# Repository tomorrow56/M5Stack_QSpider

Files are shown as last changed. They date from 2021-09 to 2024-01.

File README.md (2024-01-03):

# M5Stack_QSpider

## Quadruped Spider Robot for M5Stack
It is a quadruped walking robot using M5Stack and nine toy servos (SG90). It utilizes a custom servo module board for M5Stack equipped with PCA9685.

M5Stackとトイサーボ(SG90)x9個を使用した四脚歩行ロボットです。PCA9685を搭載したM5Stack用の自作サーボモジュール基板を使用しています。

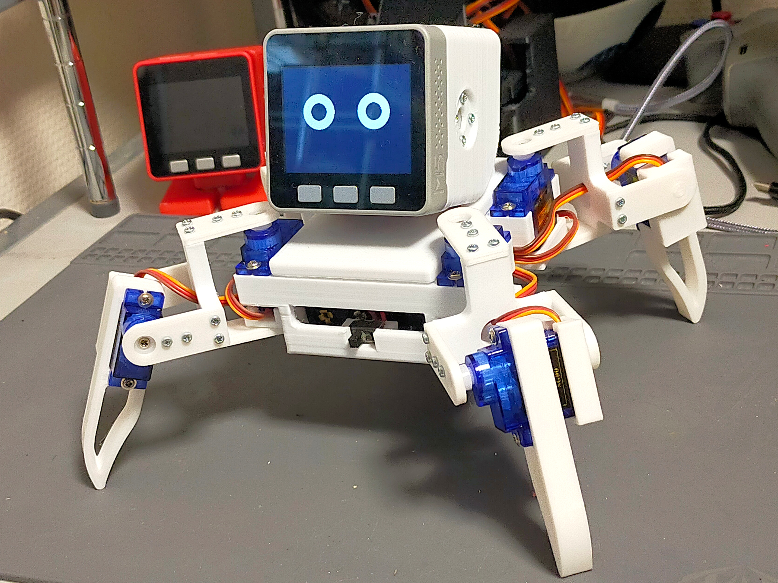
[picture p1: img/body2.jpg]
Body


Botttom View
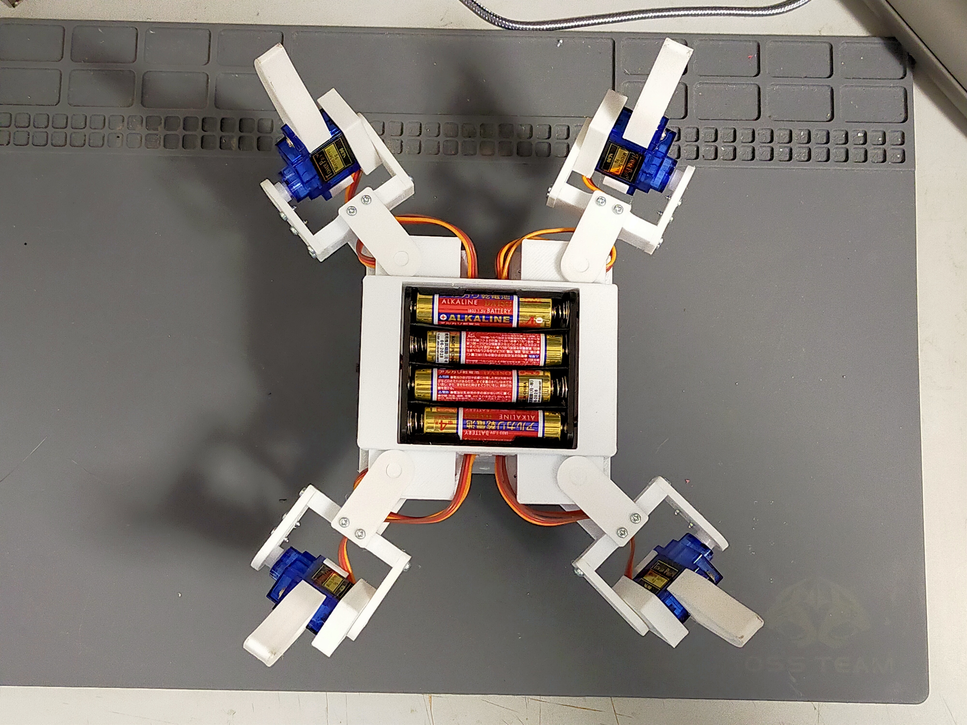
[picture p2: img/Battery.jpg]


### 3D Print Data
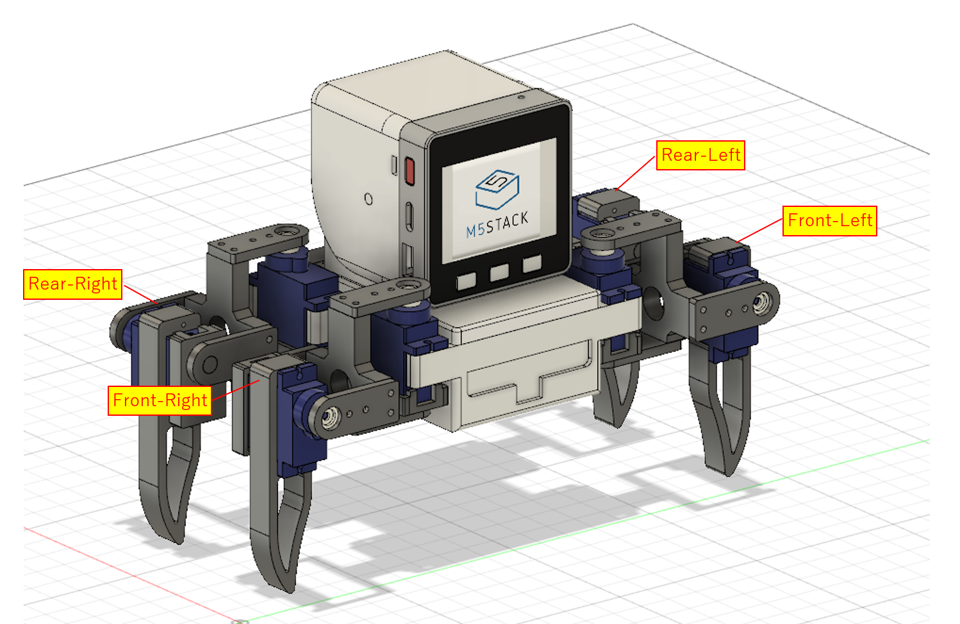
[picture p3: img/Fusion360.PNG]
Design


The 3D print data is available below. Please print four sets of parts from the 'leg' folder, as each set corresponds to one leg.

3Dプリント用のデータは以下にあります。legフォルダ以下の部品は1本分なので4個印刷してください。

[STL Data](3dprint/)

The fully assembled main body and each leg (two types, diagonal combinations) is uploaded in STEP format. Please refer to them during assembly.

組立済の本体全体・各脚(対角の組合せで2種類)はSTEP形式でアップロードしてありますので、参考にしてください。

[STEP Data](3dprint/step)

### M5Stack Servo Driver Module M5Stack用サーボモジュール基板 
The circuit diagram and Gerber data have been published below for public access.

回路図とガーバーデータは以下で公開しています。

<https://github.com/tomorrow56/M5Stack_Servo_Driver>

### Parts needed (excluding 3D print parts)
* M5Stack Basic x 1
* [SG-90](https://akizukidenshi.com/catalog/g/gM-08761/) X 9
* [Battery Holder for 4x AA](https://akizukidenshi.com/catalog/g/gP-03087/) (For servo power)
* [NP-40 Lithium-ion Battery for Cameras](https://amzn.to/3S4qocj) or a similarly sized one (For M5Stack power)
* [Slide Switch 1 Circuit 2 Contacts](https://akizukidenshi.com/catalog/g/gP-15707/)
* M2x8mm Tapping Screws (Approximately 40)
* Wiring Lead for connections

### 必要な部品 (3Dプリント部品以外) 
* M5Stack Basic x 1
* [SG-90](https://akizukidenshi.com/catalog/g/gM-08761/) X 9
* [電池ボックス単4×4本](https://akizukidenshi.com/catalog/g/gP-03087/) (サーボ電源用)
* [カメラ用リチウムイオン電池 NP-40](https://amzn.to/3S4qocj) または同サイズのもの (M5Stack電源用)
* [スライドスイッチ 1回路2接点](https://akizukidenshi.com/catalog/g/gP-15707/)
* M2x8mmのタッピングビス(約40本)
* 配線用リード線

## ソフトウエア: Software
There are sketches for ArduinoIDE in the 'examples' folder. There are two types available for web interface and ESP-NOW.

ArduinoIDE用のスケッチがexample以下にあります。Webインターフェース用とESP-NOW用の2種類があります。

### Controler with Web Interface Webインターフェース
It starts as a WiFi access point and can be controlled from a web browser.

WiFiのアクセスポイントとして起動し、Webブラウザからコントロールできます。

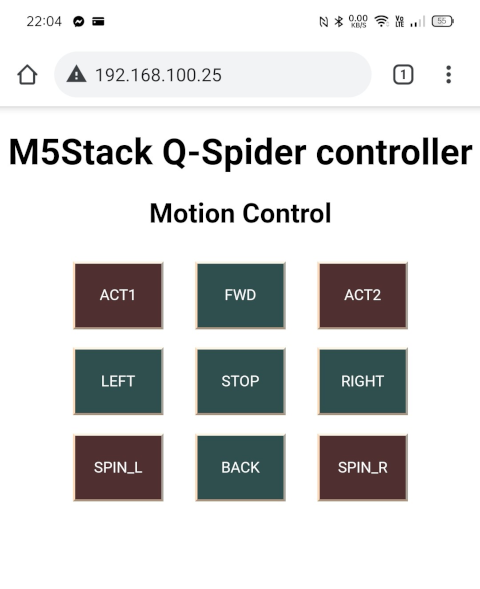
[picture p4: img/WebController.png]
Controller


### Controller for ESP-NOW mode ESP-NOW用コントローラ
The source code for the ESP-NOW controller is available below. Here, a modified Famicom controller is used.

ESP-NOW用コントローラのソースコードは以下にあります。ここではファミコン用コントローラを改造して使用しています。

<https://github.com/tomorrow56/M5AtomPad>

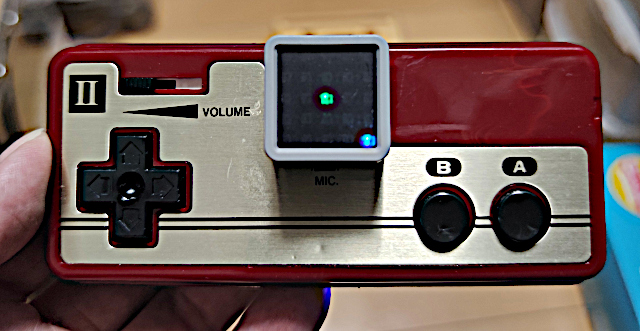
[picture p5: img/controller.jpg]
M5AtomPad


### Protopedia
<https://protopedia.net/prototype/2464>

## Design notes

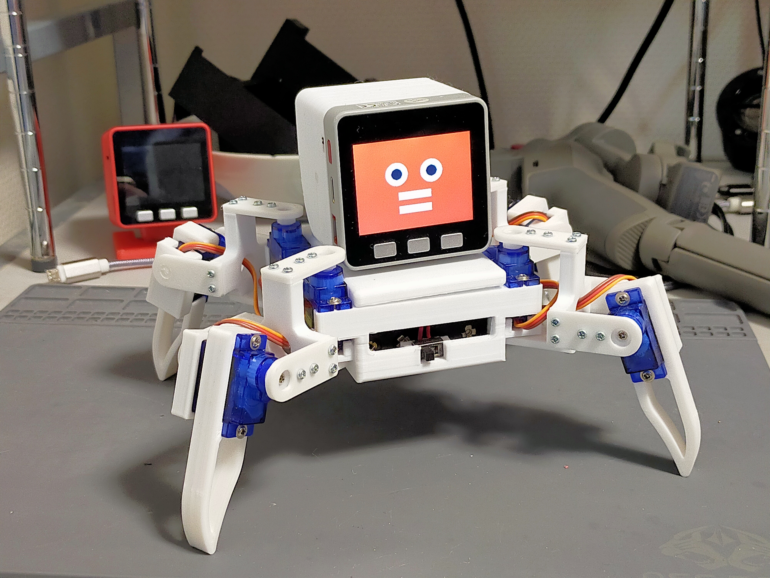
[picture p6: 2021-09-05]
img/body.jpg

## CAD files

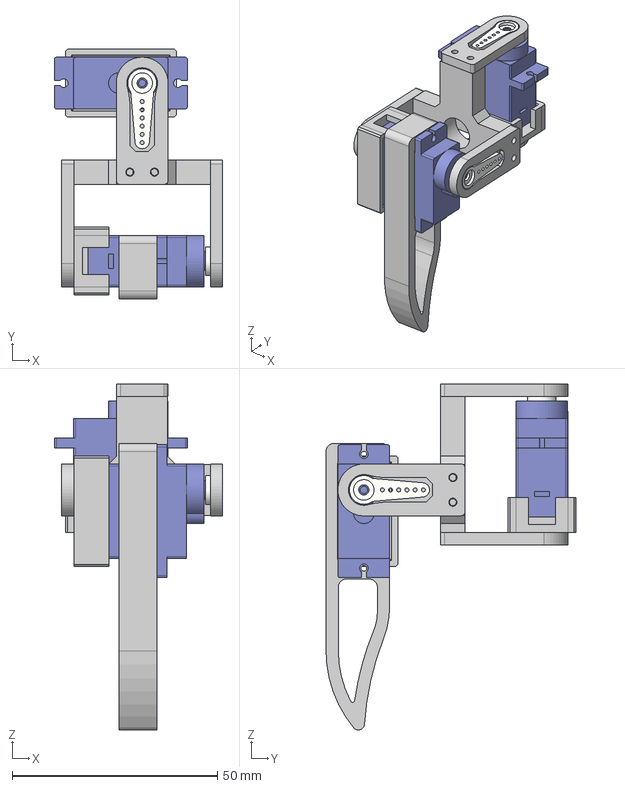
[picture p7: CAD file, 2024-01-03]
3dprint/step/assembled_Leg_FrontRight_RearLeft.step
41.0 x 60.9 x 84.3 mm
leg
SG90 v1
サーボホーン x 2
Foot_joint
shaft_top2
SG90 v1 (1)
shaft_top1
bottom_Spacer2
shaft_bottom2
shaft_bottom1
bottom_Spacer1

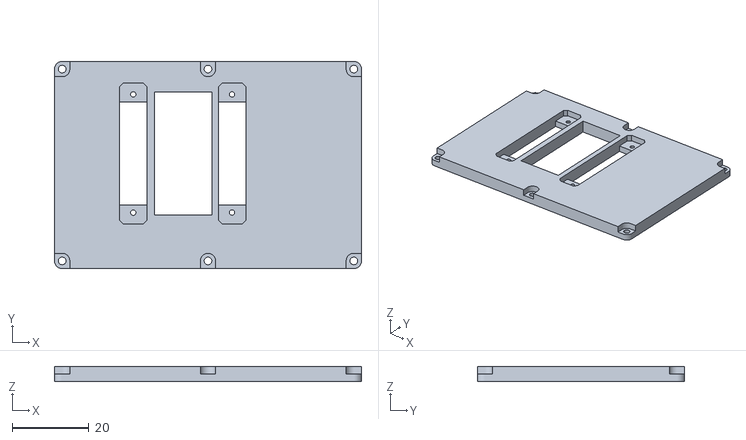
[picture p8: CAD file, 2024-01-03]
3dprint/body/body_top.stl
80.0 x 54.0 x 4.00

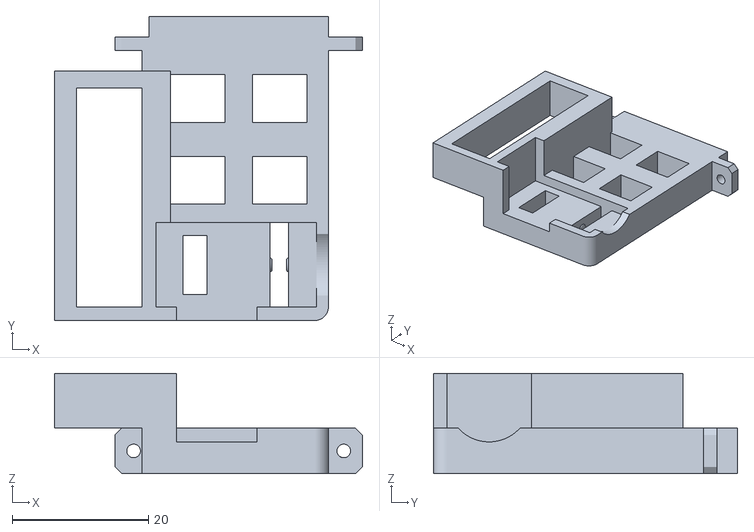
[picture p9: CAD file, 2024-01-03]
3dprint/bracket/bracket_front.stl
45.1 x 44.6 x 14.7

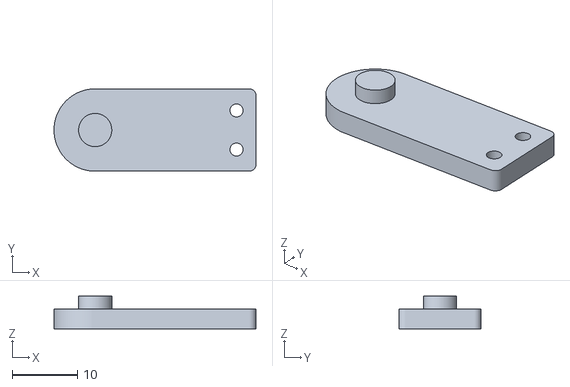
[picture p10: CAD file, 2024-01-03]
3dprint/leg/shaft_bottom1.stl
31.0 x 12.6 x 5.00

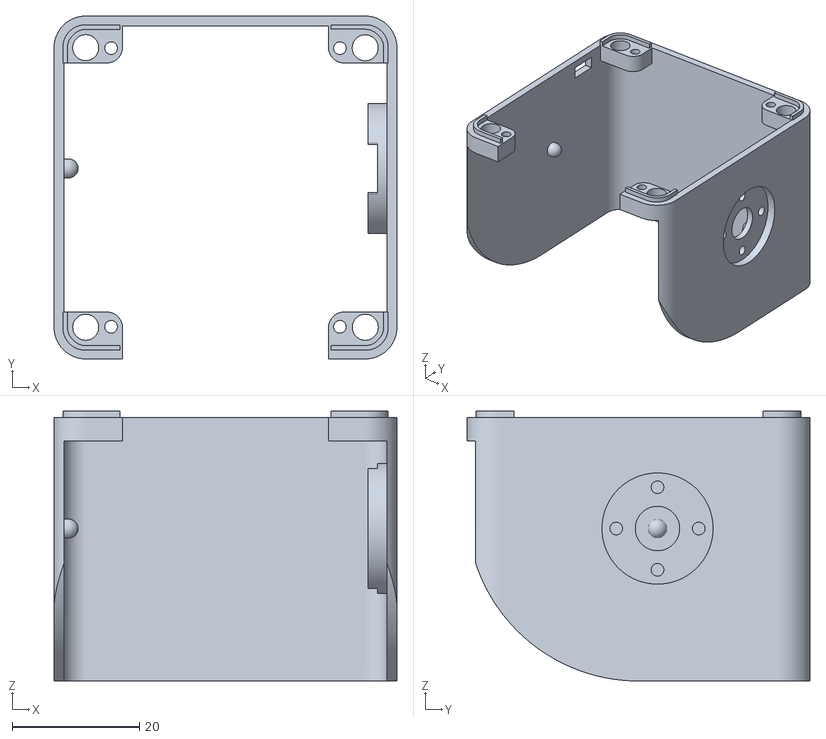
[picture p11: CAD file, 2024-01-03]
3dprint/shell/shell.stl
54.0 x 54.0 x 42.5

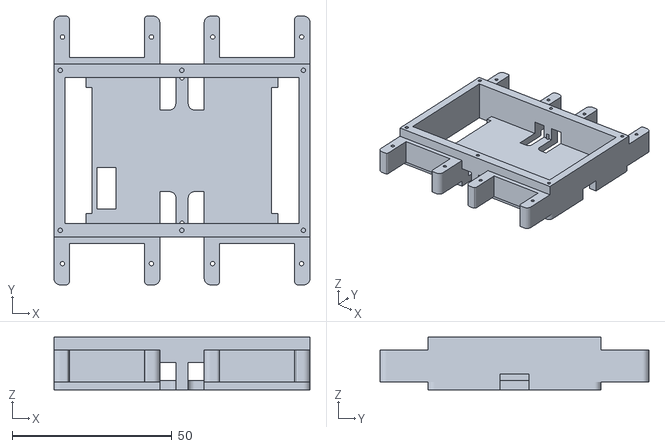
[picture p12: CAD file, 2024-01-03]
3dprint/body/body_bottom.stl
80.0 x 84.0 x 16.5

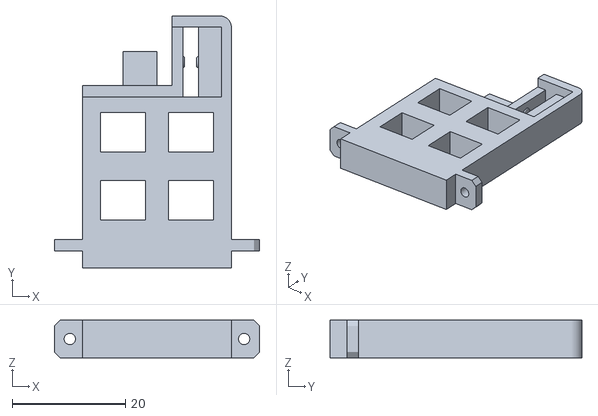
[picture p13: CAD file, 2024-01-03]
3dprint/bracket/bracket_rear.stl
36.3 x 44.6 x 6.65

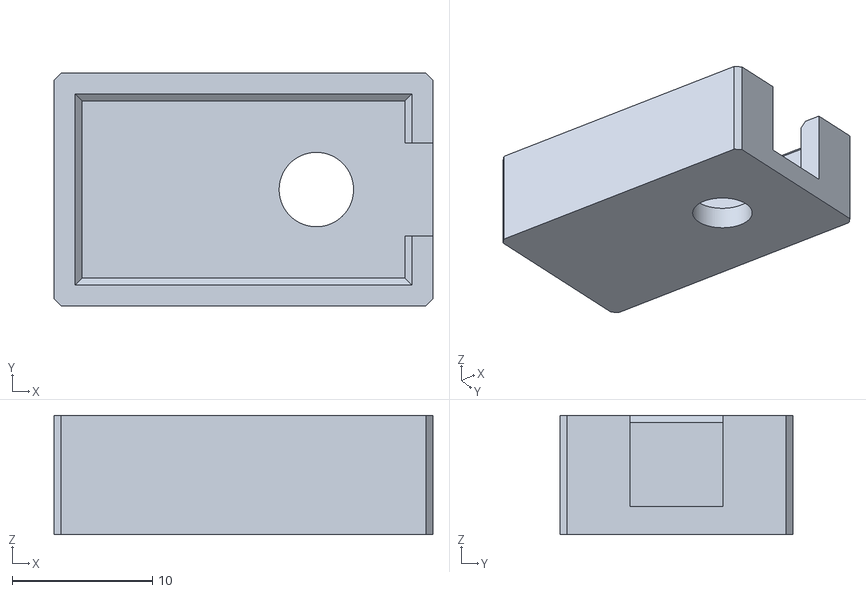
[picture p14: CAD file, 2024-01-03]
3dprint/leg/bottom_spacer1.stl
27.0 x 16.6 x 8.50

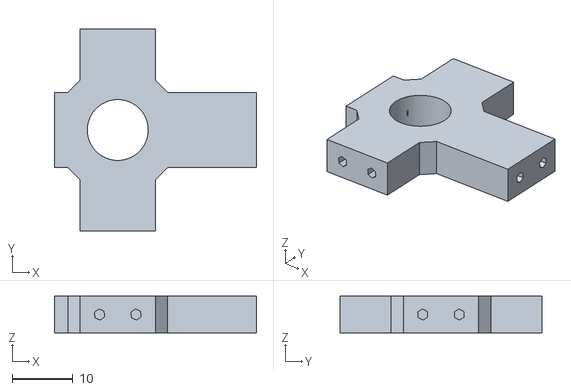
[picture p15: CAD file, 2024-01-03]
3dprint/leg/Foot_joint.stl
33.2 x 33.2 x 6.00

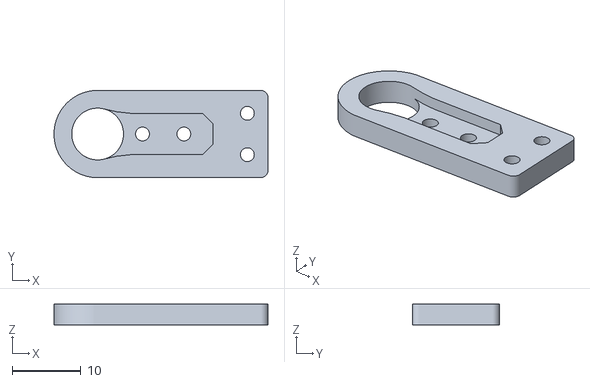
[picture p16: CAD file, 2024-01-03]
3dprint/leg/shaft_top1.stl
31.0 x 12.6 x 3.00

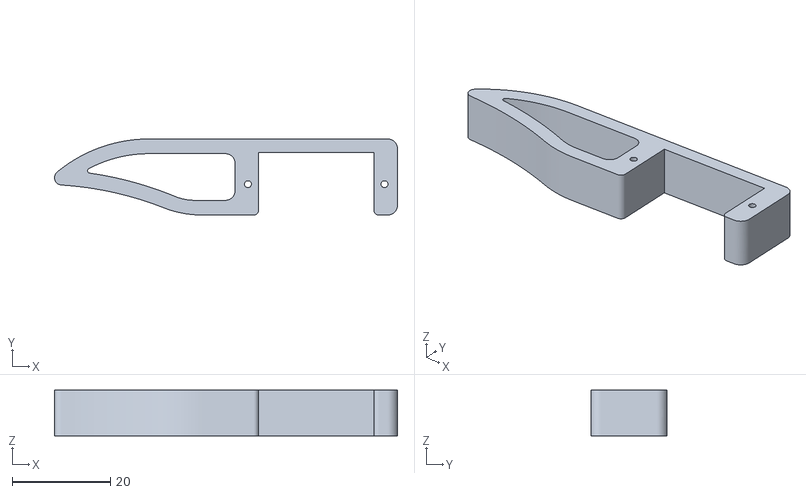
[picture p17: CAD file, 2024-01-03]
3dprint/leg/leg.stl
69.8 x 15.5 x 9.30

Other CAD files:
3dprint/step/assembled_Leg_FrontLeft_RearRight.step

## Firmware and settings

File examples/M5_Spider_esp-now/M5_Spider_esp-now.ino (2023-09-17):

#include <M5Stack.h>
#include "M5StackUpdater.h"
#include "ip5306.h"

#include <NESpad.h>
#include <esp_now.h>
#include <WiFi.h>

#include <Adafruit_PWMServoDriver.h>
#include "clappyavator.h"

//#define chgDET
#define DEBUG

/********************
 * NESPad parameters
 ********************/
#define nesStrobe 22
#define nesClock 19
#define nesData 23
NESpad nintendo = NESpad(nesStrobe,nesClock,nesData);
byte state = 0;

/********************
 * ESPNow settings
 ********************/
esp_now_peer_info_t slave;
int modeNES = 1;  //0:Multicast, 1:M5SpiderW, 2:M5SpiderB, other: Multicast
esp_err_t result;
boolean sending = false;

// command from Master
#define rNES_STOP 0
#define rNES_A 1
#define rNES_B 2
#define rNES_SELECT 3
#define rNES_START 4
#define rNES_UP 5
#define rNES_DOWN 6
#define rNES_LEFT 7
#define rNES_RIGHT 8

/********************************
* for Servo control
*********************************/
Adafruit_PWMServoDriver pwm = Adafruit_PWMServoDriver(0x72);

const uint8_t motorInterval = 30;  //[ms]

// Published values for SG90 servos; 0-180 deg
int minUs = 500;
int maxUs = 2400;

// Servo assign to each channel
#define FR0 0   // knees
#define FL0 2
#define RR0 6
#define RL0 8

#define FR1 1   // leg
#define FL1 3
#define RR1 7
#define RL1 9

#define TILT 4

// center position calibration(0-180 deg)
#define OFST 20

uint8_t CENT_FR0 = 90 + OFST;   // knees UP ++
uint8_t CENT_FL0 = 90 - OFST;   // knees UP --
uint8_t CENT_RR0 = 90 - OFST;   // knees UP --
uint8_t CENT_RL0 = 90 + OFST;   // knees UP ++

uint8_t CENT_FR1 = 90;   // leg forward ++
uint8_t CENT_FL1 = 90;   // leg forward --
uint8_t CENT_RR1 = 90;   // leg backword ++
uint8_t CENT_RL1 = 90;   // leg backword --

uint8_t CENT_TILT = 90; // up --

#define ROTATEIN  40
#define ROTATEOUT  150

int stp = 3;
int smooth = 5;

int stepInterval = 50;
int stepIntervalTurn = 100;

boolean moveFlag = false;
boolean walkFwdFlag = false;
boolean walkBckFlag = false;
boolean walkLeftFlag = false;
boolean walkRightFlag = false;
boolean spinLeftFlag = false;
boolean spinRightFlag = false;

//String Face = "/GALLERY/KumaMCN.jpg";

Avator *avator;

/************************************
 * Update Avator Task
 ************************************/
void avatorUpdate(void* arg) {
  int cnt = 0;
  while (1) {
    if(cnt == 0){
      //avator->openMouth(15);
    }
    if (cnt % 100 == 97){
      avator->openEye(false);
    }
    if (cnt % 100 == 0){
      avator->openEye(true);
      cnt = random(100);
    }
    cnt++;
    vTaskDelay(50);
  }
}

// 受信コールバック
void OnDataRecv(const uint8_t *mac_addr, const uint8_t *data, int data_len) {
  char macStr[18];
  snprintf(macStr, sizeof(macStr), "%02X:%02X:%02X:%02X:%02X:%02X",
           mac_addr[0], mac_addr[1], mac_addr[2], mac_addr[3], mac_addr[4], mac_addr[5]);
  Serial.printf("Last Packet Recv from: %s\n", macStr);
  Serial.printf("Last Packet Recv Data(%d): ", data_len);
  for ( int i = 0 ; i < data_len ; i++ ) {
    Serial.print(data[i]);
    Serial.print(" ");
  }
  Serial.println("");

// 送信元でフィルタ
  if((String)macStr == "4C:75:25:C6:F8:0C" || (String)macStr == "D8:A0:1D:5B:D1:AC"){
    if(data[0] == rNES_A){
      Serial.println("NES_A");
      spinRightFlag = true;
      #ifdef DEBUG
        Serial.println("Spin Right");
      #endif
    }else if(data[0] == rNES_B){
      Serial.println("NES_B");
      spinLeftFlag = true;
      #ifdef DEBUG
        Serial.println("Spin Left");
      #endif
    }else if(data[0] == rNES_SELECT){
      Serial.println("NES_SELECT");
    }else if(data[0] == rNES_START){
      Serial.println("NES_START");
    }else if(data[0] == rNES_UP){
      Serial.println("NES_UP");
      walkFwdFlag = true;
      #ifdef DEBUG
        Serial.println("Walk Forward");
      #endif
    }else if(data[0] == rNES_DOWN){
      Serial.println("NES_DOWN");
      walkBckFlag = true;
      #ifdef DEBUG
        Serial.println("Walk Backward");
      #endif
    }else if(data[0] == rNES_LEFT){
      Serial.println("NES_LEFT");
      walkLeftFlag = true;
      #ifdef DEBUG
        Serial.println("Walk Left");
      #endif
    }else if(data[0] == rNES_RIGHT){
      Serial.println("NES_RIGHT");
      walkRightFlag = true;
      #ifdef DEBUG
        Serial.println("Walk Right");
      #endif
    }else if(data[0] == rNES_STOP){
      Serial.println("NES_STOP");
      walkStop();
    }else{
      Serial.println("Unknown");
    }
  }
}

/************************************
 * Arduino block
 ************************************/
void setup() {
  // M5Stack::begin(LCDEnable, SDEnable, SerialEnable, I2CEnable);
  M5.begin(true, true, true, true);
  M5.Power.begin();
  M5.Power.setVinMaxCurrent(CURRENT_400MA);

  M5.Speaker.begin();
  M5.Speaker.mute();
  M5.Speaker.end();

  if(digitalRead(BUTTON_A_PIN) == 0) {
    Serial.println("Will Load menu binary");
    updateFromFS(SD);
    ESP.restart();
  }

  Serial.println("M5Stack Q-Spider esp-now");
  Serial.printf("NES mode: %d\n", modeNES);

/*
 * Servo setup
 */
 //modeNES 1:M5SpiderW, 2:M5SpiderB
  if(modeNES == 1){
    CENT_FR0 = 90 + OFST;   // knees UP ++
    CENT_FL0 = 90 - OFST;   // knees UP --
    CENT_RR0 = 90 - OFST;   // knees UP --
    CENT_RL0 = 90 + OFST;   // knees UP ++
    CENT_FR1 = 90;   // leg forward ++
    CENT_FL1 = 90;   // leg forward --
    CENT_RR1 = 90;   // leg backword ++
    CENT_RL1 = 90;   // leg backword --
    CENT_TILT = 100; // up --
  }else if(modeNES == 2){
    CENT_FR0 = 85 + OFST;   // knees UP ++
    CENT_FL0 = 85 - OFST;   // knees UP --
    CENT_RR0 = 95 - OFST;   // knees UP --
    CENT_RL0 = 90 + OFST;   // knees UP ++
    CENT_FR1 = 85;   // leg forward ++
    CENT_FL1 = 90;   // leg forward --
    CENT_RR1 = 90;   // leg backword ++
    CENT_RL1 = 95;   // leg backword --
    CENT_TILT = 110; // up --
  }

  pwm.begin();
  pwm.setPWMFreq(50);  // Analog servos run at 50 Hz updates
  delay(10);

  Serial.println("Ready");

  avator = new Avator();
  M5.Lcd.fillScreen(SECONDARY_COLOR);
//  M5.Lcd.drawJpgFile(SD, Face.c_str(), 0, 0, 320, 240);
  avator->init();

/*
 * Demo action
 */
//  servoDemo();
  servoHome();

  #ifdef chgDET
    if(getChargeEnable()){
      adjMode();
    }
  #endif

  walkStop();

  // ESP-NOW初期化
  WiFi.mode(WIFI_STA);
  WiFi.disconnect();
  if (esp_now_init() == ESP_OK) {
    Serial.println("ESPNow Init Success");
  } else {
    Serial.println("ESPNow Init Failed");
    ESP.restart();
  }

// ESP-NOWコールバック登録
  esp_now_register_recv_cb(OnDataRecv);

  // xTaskCreatePinnedToCore(タスクの関数名,"タスク名",スタックメモリサイズ,NULL,タスク優先順位,タスクハンドルポインタ,Core ID);
  // xTaskCreatePinnedToCore(func,"name",Stuck size,NULL,priority,Task pointer,Core ID)
  // Core ID: 0 or 1 or tskNO_AFFINITY
  xTaskCreatePinnedToCore(avatorUpdate, "Task0", 4096, NULL, 1, NULL, 0);
}

void loop(){
  M5.update();

  if(walkFwdFlag == true){
    if(moveFlag == false){
      walkFwdInit();
      moveFlag = true;
    }
    stepFoward();
  }

  if(walkBckFlag == true){
    if(moveFlag == false){
      walkBckInit();
      moveFlag = true;
    }
    stepBackward();
  }

  if(walkLeftFlag == true){
    if(moveFlag == false){
      walkLeftInit();
      moveFlag = true;
    }
    stepLeft();
  }

  if(walkRightFlag == true){
    if(moveFlag == false){
      walkRightInit();
      moveFlag = true;
    }
    stepRight();
  }

  if(spinLeftFlag == true){
    if(moveFlag == false){
      spinLeftInit();
      moveFlag = true;
    }
    stepSpinLeft();
  }

  if(spinRightFlag == true){
    if(moveFlag == false){
      spinRightInit();
      moveFlag = true;
    }
    stepSpinRight();
  }

}

/************************************
 * Demo Action
 ************************************/
// Servo Demo
void servoDemo(){
  servoHome();
  delay(500);

  servoLegOpen(45);
  delay(500);
  servoStandUp(70);
  delay(500);
  servoLegClose(45);
  delay(500);
  servoLayDown(70);
  delay(500);

  walkStop();
  delay(500);

  servoTilt(10);
  delay(500);
  servoTilt(0);
}

// Home position
void servoHome(){
  moveServo(TILT, 0);

  moveServo(FR1, 0);
  moveServo(FL1, 0);
  moveServo(RR1, 0);
  moveServo(RL1, 0);

  moveServo(FR0, 0);
  moveServo(FL0, 0);
  moveServo(RR0, 0);
  moveServo(RL0, 0);
}

/************************************
 * Stop
 ************************************/
void walkStop(){
  walkFwdFlag = false;
  walkBckFlag = false;
  walkLeftFlag = false;
  walkRightFlag = false;
  spinLeftFlag = false;
  spinRightFlag = false;

  moveFlag = false;
  walkEnd();

  #ifdef DEBUG
    Serial.println("Walk Stop");
  #endif
}

// END position
void walkEnd(){
  delay(stepInterval);
  servoLegFront(45);
  servoLegRear(45);
  servoKneesAll(70);
}

/************************************
 * Walk
 ************************************/
// Walk Forward
void walkFwdInit(){
  servoLegFront(45);
  servoLegRear(45);
  servoKneesAll(70);
  delay(stepInterval);

  // initial position for walk Forward
  moveServo(RL0, -50);
  moveServo(RL1, 0);
  delay(stepInterval);
  moveServo(RL0, -70);
}

void stepFoward(){
  moveServo(FL0, -50);
  moveServo(RR0, -50);
  delay(stepInterval);

  moveServo(FL1, 45);
  delay(stepInterval);

  moveServo(FR1, 0);
  moveServo(RL1, 45);
  delay(stepInterval);

  moveServo(RR1, 0);
  delay(stepInterval);

  moveServo(FL0, -70);
  moveServo(RR0, -70);
  delay(stepInterval);

  moveServo(FR0, -50);
  moveServo(RL0, -50);
  delay(stepInterval);

  moveServo(FR1, 45);
  delay(stepInterval);

  moveServo(FL1, 0);
  moveServo(RR1, 45);
  delay(stepInterval);

  moveServo(RL1, 0);
  delay(stepInterval);

  moveServo(FR0, -70);
  moveServo(RL0, -70);
  delay(stepInterval);
}

// Walk Backward
void walkBckInit(){
  servoLegFront(45);
  servoLegRear(45);
  servoKneesAll(70);
  delay(stepInterval);

  // initial position for walk Back
  moveServo(FR0, -50);
  moveServo(FR1, 0);
  delay(stepInterval);
  moveServo(FR0, -70);
}

void stepBackward(){
  moveServo(FL0, -50);
  moveServo(RR0, -50);
  delay(stepInterval);

  moveServo(RR1, 45);
  delay(stepInterval);

  moveServo(FR1, 45);
  moveServo(RL1, 0);
  delay(stepInterval);

  moveServo(FL1, 0);
  delay(stepInterval);

  moveServo(FL0, -70);
  moveServo(RR0, -70);
  delay(stepInterval);

  moveServo(FR0, -50);
  moveServo(RL0, -50);
  delay(stepInterval);

  moveServo(RL1, 45);
  delay(stepInterval);

  moveServo(FL1, 45);
  moveServo(RR1, 0);
  delay(stepInterval);

  moveServo(FR1, 0);
  delay(stepInterval);

  moveServo(FR0, -70);
  moveServo(RL0, -70);
  delay(stepInterval);
}

// Walk Left
void walkLeftInit(){
  servoLegFront(45);
  servoLegRear(45);
  servoKneesAll(70);
  delay(stepInterval);

  // initial position for walk Left
  moveServo(FR0, -50);
  moveServo(FR1, 90);
  delay(stepInterval);
  moveServo(FR0, -70);
}

void stepLeft(){
  moveServo(FL0, -50);
  moveServo(RR0, -50);
  delay(stepInterval);

  moveServo(FL1, 45);
  delay(stepInterval);

  moveServo(FR1, 45);
  moveServo(RL1, 90);
  delay(stepInterval);

  moveServo(RR1, 90);
  delay(stepInterval);

  moveServo(FL0, -70);
  moveServo(RR0, -70);
  delay(stepInterval);

  moveServo(FR0, -50);
  moveServo(RL0, -50);
  delay(stepInterval);

  moveServo(RL1, 45);
  delay(stepInterval);

  moveServo(FL1, 90);
  moveServo(RR1, 45);
  delay(stepInterval);

  moveServo(FR1, 90);
  delay(stepInterval);

  moveServo(FR0, -70);
  moveServo(RL0, -70);
  delay(stepInterval);
}

// Walk Right
void walkRightInit(){
  servoLegFront(45);
  servoLegRear(45);
  servoKneesAll(70);
  delay(stepInterval);

  // initial position for walk Right
  moveServo(RL0, -50);
  moveServo(RL1, 90);
  delay(stepInterval);
  moveServo(RL0, -70);
}

void stepRight(){
  moveServo(FL0, -50);
  moveServo(RR0, -50);
  delay(stepInterval);

  moveServo(RR1, 45);
  delay(stepInterval);

  moveServo(RL1, 45);
  moveServo(FR1, 90);
  delay(stepInterval);

  moveServo(FL1, 90);
  delay(stepInterval);

  moveServo(FL0, -70);
  moveServo(RR0, -70);
  delay(stepInterval);

  moveServo(FR0, -50);
  moveServo(RL0, -50);
  delay(stepInterval);

  moveServo(FR1, 45);
  delay(stepInterval);

  moveServo(FL1, 45);
  moveServo(RR1, 90);
  delay(stepInterval);

  moveServo(RL1, 90);
  delay(stepInterval);

  moveServo(FR0, -70);
  moveServo(RL0, -70);
  delay(stepInterval);
}

/************************************
 * Spin
 ************************************/
// Spin Left
void spinLeftInit(){
  servoLegFront(45);
  servoLegRear(45);
  servoKneesAll(70);
  delay(stepIntervalTurn);
}

void stepSpinLeft(){
  moveServo(FR0, -50);
  moveServo(RL0, -50);
  moveServo(FR1, 90);
  moveServo(RL1, 90);
  moveServo(FL1, 90);
  moveServo(RR1, 90);
  delay(stepIntervalTurn);

  moveServo(FR0, -70);
  moveServo(RL0, -70);
  delay(stepIntervalTurn);

  moveServo(FL0, -50);
  moveServo(RR0, -50);
  moveServo(FL1, 45);
  moveServo(RR1, 45);
  moveServo(FR1, 45);
  moveServo(RL1, 45);
  delay(stepIntervalTurn);

  moveServo(FL0, -70);
  moveServo(RR0, -70);
  delay(stepIntervalTurn);
}

// Spin Right
void spinRightInit(){
  servoLegFront(45);
  servoLegRear(45);
  servoKneesAll(70);
  delay(stepIntervalTurn);
}

void stepSpinRight(){
  moveServo(FL0, -50);
  moveServo(RR0, -50);
  moveServo(FR1, 90);
  moveServo(RL1, 90);
  moveServo(FL1, 90);
  moveServo(RR1, 90);
  delay(stepIntervalTurn);

  moveServo(FL0, -70);
  moveServo(RR0, -70);
  delay(stepIntervalTurn);

  moveServo(FR0, -50);
  moveServo(RL0, -50);
  moveServo(FL1, 45);
  moveServo(RR1, 45);
  moveServo(FR1, 45);
  moveServo(RL1, 45);
  delay(stepIntervalTurn);

  moveServo(FR0, -70);
  moveServo(RL0, -70);
  delay(stepIntervalTurn);
}

/************************************
 * fixed action
 ************************************/
// all knees angle
void servoKneesAll(int ang){
  int i = (-1 * ang);
  moveServo(FR0, i);
  moveServo(FL0, i);
  moveServo(RR0, i);
  moveServo(RL0, i);
}

// front leg angle
void servoLegFront(int ang){
  int i = ang;
  moveServo(FR1, i);
  moveServo(FL1, i);
}

// Rear leg angle
void servoLegRear(int ang){
  int i = ang;
  moveServo(RR1, i);
  moveServo(RL1, i);
}

// Stand Up
void servoStandUp(int ang){
  int i = 0;
  while(i < ang){
    servoKneesAll(i);
    i = i + stp;
    delay(smooth);
  }
}

// Lay Down
void servoLayDown(int ang){
  // lay down
  int i = ang;
  while(i > 0){
    servoKneesAll(i);
    i = i - stp;
    delay(smooth);
  }
}

// Leg Open
void servoLegOpen(int ang){
  int i = 0;
  while(i < ang){
    servoLegFront(i);
    servoLegRear(i);
    i = i + stp;
    delay(smooth);
  }
}

// Leg Close
void servoLegClose(int ang){
  int i = ang;
  // leg close
  while(i > 0){
    servoLegFront(i);
    servoLegRear(i);
    i = i - stp;
    delay(smooth);
  }
}

// Tilt
void servoTilt(int ang){
  moveServo(TILT, ang);
}

/************************************
 * Servo position by angle
 ************************************/
void moveServo(int n, int deltaAngle){
  if(n == TILT){
     setServoAngle(n, CENT_TILT - deltaAngle);
  }else if(n == FR1){
     setServoAngle(n, CENT_FR1 + deltaAngle);
  }else if(n == FL1){
     setServoAngle(n, CENT_FL1 - deltaAngle);
  }else if(n == RR1){
     setServoAngle(n, CENT_RR1 - deltaAngle);
  }else if(n == RL1){
     setServoAngle(n, CENT_RL1 + deltaAngle);
  }else if(n == FR0){
     setServoAngle(n, CENT_FR0 + deltaAngle);
  }else if(n == FL0){
     setServoAngle(n, CENT_FL0 - deltaAngle);
  }else if(n == RR0){
     setServoAngle(n, CENT_RR0 - deltaAngle);
  }else if(n == RL0){
     setServoAngle(n, CENT_RL0 + deltaAngle);
  }
}

/*************************************************** 
 you can use this function if you'd like to set the pulse length in microsecond
***************************************************/
void setServoPulse(uint8_t n, double pulse_us){
  double pulselength;
  
  pulselength = 1000000;   // 1,000,000 us per second
  pulselength /= 50;   // 50 Hz
//  Serial.print(pulselength); Serial.println(" us per period"); 
  pulselength /= 4096;  // 12 bits of resolution
//  Serial.print(pulselength); Serial.println(" us per bit"); 
  pulse_us /= pulselength;
//  Serial.println(pulse_us);

  pwm.setPWM(n, 0, pulse_us);
}

/*************************************************** 
 you can use this function if you'd like to set the angle in degree
***************************************************/
void setServoAngle(uint8_t n, uint8_t ang){
  double pulse_us = map(ang, 0, 180, minUs, maxUs); //map angle(0～180) to pulse_us
  setServoPulse(n, pulse_us);
}

/*************************************************** 
 status of charging
 **************************************************/
void adjMode(){
    delay(300);
    M5.Lcd.fillScreen(BLACK);
    M5.Lcd.setTextSize(3);
    M5.Lcd.setTextColor(WHITE, BLACK);
    M5.Lcd.setCursor(50, 0);
    M5.Lcd.print("HOME POSITION");
    M5.Lcd.setCursor(50, 50);
    M5.Lcd.printf("NES mode: %d\n", modeNES);
    servoHome();

    #ifdef DEBUG
      Serial.println("Charging...");
    #endif

    while(1){
      M5.update();
      M5.Lcd.setCursor(10, 150);
      if(getChargeEnable()){
        switch(getChargeMode()){
          case 1:
            M5.Lcd.print("Full Charge          ");
            break;
          case 2:
            M5.Lcd.print("Charging(CV mode)    ");
            break;
          case 3:
            M5.Lcd.print("Charging(CC mode)    ");
            break;
          default:
            M5.Lcd.print("Unknown mode         ");
            break;
        }
      }else{
        M5.Lcd.print("                     ");
      }

      uint8_t Level =  M5.Power.getBatteryLevel();
      if(Level > 100){
        Level = 100;
      }else if(Level < 0){
        Level = 0;
      }
      M5.Lcd.progressBar(30, 200, 260, 20, Level);
      M5.Lcd.drawRect(29, 199, 262, 22, WHITE);

      if(M5.BtnB.wasPressed()){
        M5.Lcd.fillScreen(SECONDARY_COLOR);
//        M5.Lcd.drawJpgFile(SD, Face.c_str(), 0, 0, 320, 240);
        avator->init();
        break;
      }
      delay(100);
   }
}

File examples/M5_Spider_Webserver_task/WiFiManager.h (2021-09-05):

/**************************************************************
   WiFiManager is a library for the ESP8266/Arduino platform
   (https://github.com/esp8266/Arduino) to enable easy
   configuration and reconfiguration of WiFi credentials using a Captive Portal
   inspired by:
   http://www.esp8266.com/viewtopic.php?f=29&t=2520
   https://github.com/chriscook8/esp-arduino-apboot
   https://github.com/esp8266/Arduino/tree/master/libraries/DNSServer/examples/CaptivePortalAdvanced
   Built by AlexT https://github.com/tzapu
   Licensed under MIT license
 **************************************************************/

#ifndef WiFiManager_h
#define WiFiManager_h

#if defined(ESP8266)
#include <ESP8266WiFi.h>
#include <ESP8266WebServer.h>
#else
#include <WiFi.h>
#include <WebServer.h>
#endif
#include <DNSServer.h>
#include <memory>

#if defined(ESP8266)
extern "C" {
  #include "user_interface.h"
}
#define ESP_getChipId()   (ESP.getChipId())
#else
#include <esp_wifi.h>
#define ESP_getChipId()   ((uint32_t)ESP.getEfuseMac())
#endif

const char HTTP_HEAD_START[] PROGMEM      = "<!DOCTYPE html><html lang=\"en\"><head><meta name=\"viewport\" content=\"width=device-width, initial-scale=1, user-scalable=no\"/><title>{v}</title>";
const char HTTP_STYLE[] PROGMEM           = "<style>.c{text-align: center;} div,input{padding:5px;font-size:1em;} input{width:95%;} body{text-align: center;font-family:verdana;} button{border:0;border-radius:0.3rem;background-color:#1fa3ec;color:#fff;line-height:2.4rem;font-size:1.2rem;width:100%;} .q{float: right;width: 64px;text-align: right;} .l{background: url(\"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") no-repeat left center;background-size: 1em;}</style>";
const char HTTP_SCRIPT[] PROGMEM          = "<script>function c(l){document.getElementById('s').value=l.innerText||l.textContent;document.getElementById('p').focus();}</script>";
const char HTTP_HEAD_END[] PROGMEM        = "</head><body><div style='text-align:left;display:inline-block;min-width:260px;'>";
const char HTTP_PORTAL_OPTIONS[] PROGMEM  = "<form action=\"/wifi\" method=\"get\"><button>Configure WiFi</button></form><br/><form action=\"/0wifi\" method=\"get\"><button>Configure WiFi (No Scan)</button></form><br/>";
//<form action=\"/i\" method=\"get\"><button>Info</button></form><br/><form action=\"/r\" method=\"post\"><button>Reset</button></form>";
const char HTTP_ITEM[] PROGMEM            = "<div><a href='#p' onclick='c(this)'>{v}</a>&nbsp;<span class='q {i}'>{r}%</span></div>";
const char HTTP_FORM_START[] PROGMEM      = "<form method='get' action='wifisave'><input id='s' name='s' length=32 placeholder='SSID'><br/><input id='p' name='p' length=64 type='password' placeholder='password'><br/>";
const char HTTP_FORM_PARAM[] PROGMEM      = "<br/><input id='{i}' name='{n}' length={l} placeholder='{p}' value='{v}' {c}>";
const char HTTP_FORM_END[] PROGMEM        = "<br/><button type='submit'>save</button></form>";
const char HTTP_SCAN_LINK[] PROGMEM       = "<br/><div class=\"c\"><a href=\"/wifi\">Scan</a></div>";
const char HTTP_SAVED[] PROGMEM           = "<div>Credentials Saved<br />Trying to connect Weread to network.<br />If it fails reconnect to AP to try again</div>";
const char HTTP_END[] PROGMEM             = "</div></body></html>";

#define WIFI_MANAGER_MAX_PARAMS 10

class WiFiManagerParameter {
  public:
    WiFiManagerParameter(const char *custom);
    WiFiManagerParameter(const char *id, const char *placeholder, const char *defaultValue, int length);
    WiFiManagerParameter(const char *id, const char *placeholder, const char *defaultValue, int length, const char *custom);

    const char *getID();
    const char *getValue();
    const char *getPlaceholder();
    int         getValueLength();
    const char *getCustomHTML();
  private:
    const char *_id;
    const char *_placeholder;
    char       *_value;
    int         _length;
    const char *_customHTML;

    void init(const char *id, const char *placeholder, const char *defaultValue, int length, const char *custom);

    friend class WiFiManager;
};


class WiFiManager
{
  public:
    WiFiManager();

    boolean       autoConnect();
    boolean       autoConnect(char const *apName, char const *apPassword = NULL);

    //if you want to always start the config portal, without trying to connect first
    boolean       startConfigPortal();
    boolean       startConfigPortal(char const *apName, char const *apPassword = NULL);

    // get the AP name of the config portal, so it can be used in the callback
    String        getConfigPortalSSID();
    String        getSSID();
    String        getPassword();
    void          resetSettings();

    //sets timeout before webserver loop ends and exits even if there has been no setup.
    //useful for devices that failed to connect at some point and got stuck in a webserver loop
    //in seconds setConfigPortalTimeout is a new name for setTimeout
    void          setConfigPortalTimeout(unsigned long seconds);
    void          setTimeout(unsigned long seconds);

    //sets timeout for which to attempt connecting, useful if you get a lot of failed connects
    void          setConnectTimeout(unsigned long seconds);


    void          setDebugOutput(boolean debug);
    //defaults to not showing anything under 8% signal quality if called
    void          setMinimumSignalQuality(int quality = 8);
    //sets a custom ip /gateway /subnet configuration
    void          setAPStaticIPConfig(IPAddress ip, IPAddress gw, IPAddress sn);
    //sets config for a static IP
    void          setSTAStaticIPConfig(IPAddress ip, IPAddress gw, IPAddress sn);
    //called when AP mode and config portal is started
    void          setAPCallback( void (*func)(WiFiManager*) );
    //called when settings have been changed and connection was successful
    void          setSaveConfigCallback( void (*func)(void) );
    //adds a custom parameter
    void          addParameter(WiFiManagerParameter *p);
    //if this is set, it will exit after config, even if connection is unsuccessful.
    void          setBreakAfterConfig(boolean shouldBreak);
    //if this is set, try WPS setup when starting (this will delay config portal for up to 2 mins)
    //TODO
    //if this is set, customise style
    void          setCustomHeadElement(const char* element);
    //if this is true, remove duplicated Access Points - defaut true
    void          setRemoveDuplicateAPs(boolean removeDuplicates);

  private:
    std::unique_ptr<DNSServer>        dnsServer;
#ifdef ESP8266
    std::unique_ptr<ESP8266WebServer> server;
#else
    std::unique_ptr<WebServer>        server;
#endif
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

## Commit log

2024-01-03 replaced all stl data
    [Foot_joint.stl, assembled_Leg_FrontLrft_RearRight.step, assembled_Leg_FrontRight_and_RearLeft.step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]
2026-07-11 Add PCB design data, replace STLs with STEP/F3Z, update .gitignore for draft article
2026-07-11 Update README: servo driver module now points to in-repo pcb data
2026-07-12 Fix gerber folder typo (gerver -> gerber) and replace gerber production data
2026-07-12 Add schematic PDF for M5_PCA9685_v03
2026-07-15 Update assembled STEP and F3Z files with regenerated geometry data
2026-07-15 Update README links to point to reorganized 3D print data directories
2026-08-04 Add ESP32_ChipInfo example, update READMEs, and update 3D print STEP/F3Z data
2026-10-11 Update README servo driver links to point to in-repo PCB data and refactor ESP-NOW command handling with setMoveFlag function
2026-10-11 Update parts list in README
    - Replace wiring lead with linked red/black lead
    - Add connector housing 2P
    - Add double-sided adhesive gel tape for servo bottom_Spacer
    - Remove slide switch entry from parts list
    Generated with [Devin](https://devin.ai)
2026-10-11 Add production data reference to servo module board in README
    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
2026-10-11 Update production BOM with LCSC part numbers and footprints
    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
2026-10-11 Add Switch-Science S9V11F5 links and update BOM part reference
    - README: add Switch-Science S9V11F5 purchase link in both languages
    - BOM: update J11 value to S9V11F5 and use Switch-Science URL
    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
